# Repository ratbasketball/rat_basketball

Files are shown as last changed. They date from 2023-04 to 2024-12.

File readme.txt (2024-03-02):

## Installation Instructions

# Start with a fresh install of Raspberry Pi OS (legacy, 64 bit) Debian Bullseye & Update System Packages:
sudo apt update && sudo apt upgrade -y

# Install or Upgrade pygame and pygame_menu
pip install --upgrade --force-reinstall pygame==2.3.0 

# Install RPi.GPIO
sudo pip install RPi.GPIO

# Install SDL2 Dependencies
sudo apt-get install libsdl2-mixer-2.0-0 python3-sdl2

# Without installing the above packages, you will encounter errors
# loading the required fonts to run the game, and running the program.  

## Getting the software:

# Clone the repository
git clone https://github.com/ratbasketball/rat_basketball.git

# Move Python files to the desktop
mv rat_basketball/*.py ~/Desktop/

# Clean up by removing the repository folder (optional)
rm -rf rat_basketball

## Game instructions
# Execute the file ratbasketball.py from your desktop.  
# Modify the controls.py file if necessary for your controller.

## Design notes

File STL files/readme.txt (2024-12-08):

The following is a list of 3d printed components available as .stl files in this directory:

hoop components:

	hoop.stl
	
	sensor arm v3.stl or sensor arm v4.stl
		Sensor arm v4 provides an inverted signal, while remaining otherwise identical to sensor arm v3.  
		
General components:

	pellet duct.stl: This allows the trainer to pass pellets or food to the rats
	
	get light filter slot.stl:  This part allows you to slide a gel light filter in front of an led light, to change the stimuli color.

All objects have been tested printed at 100% infill.

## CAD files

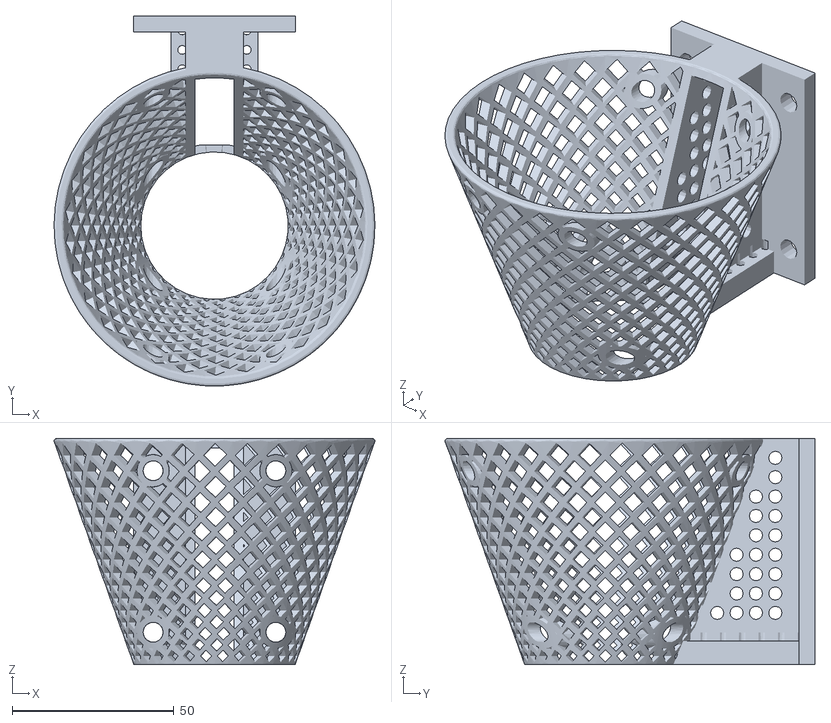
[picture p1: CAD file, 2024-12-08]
STL files/HOOP_v2.stl
99.3 x 114.5 x 70.0

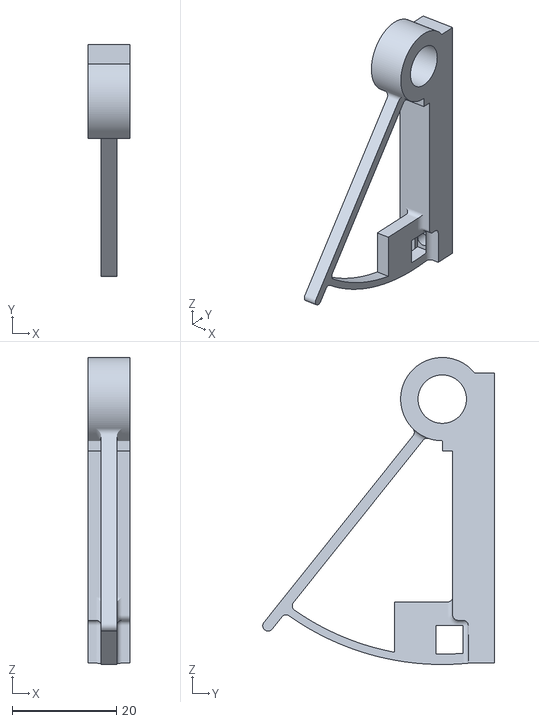
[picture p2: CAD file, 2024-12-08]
STL files/sensor arm v4.stl
8.00 x 44.5 x 59.0

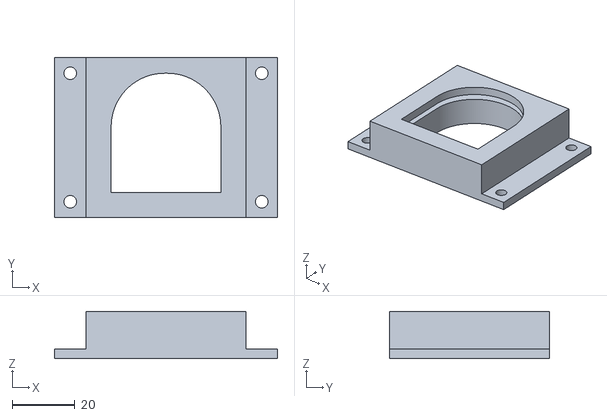
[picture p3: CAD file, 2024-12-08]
STL files/gel light filter slot.stl
70.8 x 50.8 x 15.0

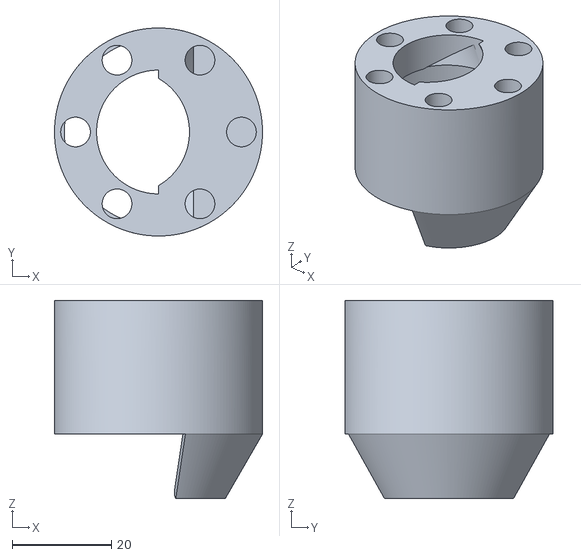
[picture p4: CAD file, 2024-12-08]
STL files/pellet duct.stl
42.0 x 42.0 x 40.0

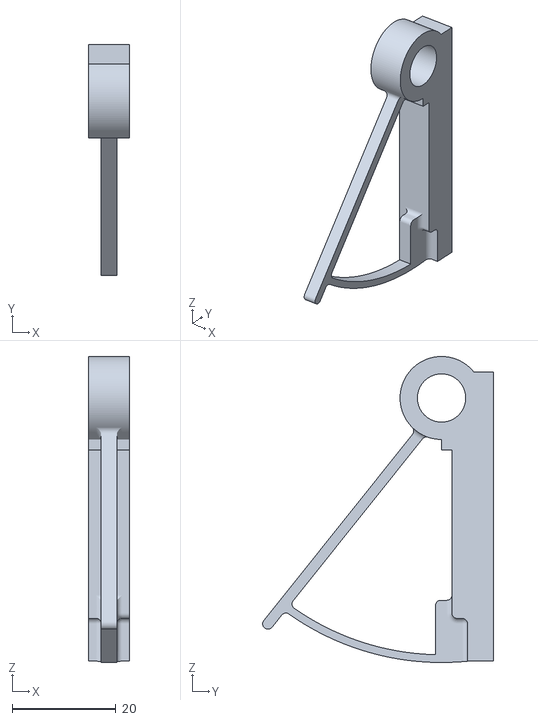
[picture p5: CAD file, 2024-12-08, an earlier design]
STL files/Archive/sensor arm v3.stl
8.00 x 44.5 x 59.0

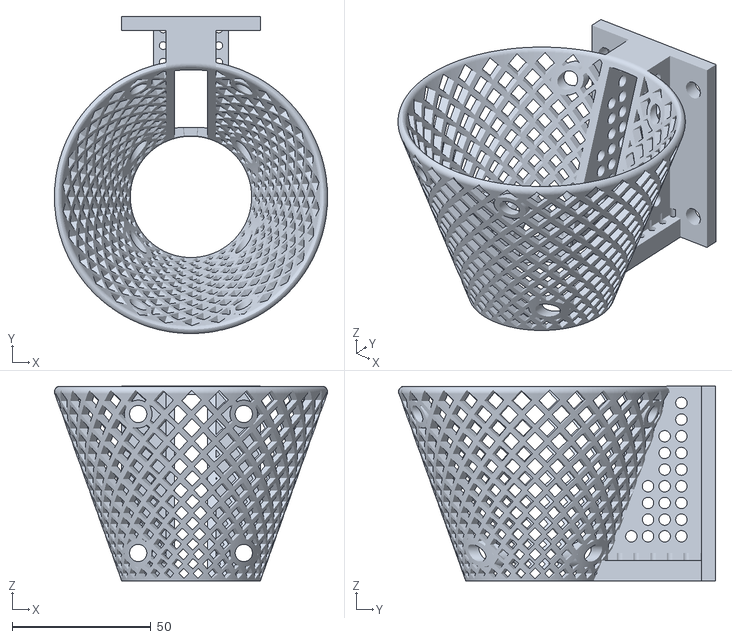
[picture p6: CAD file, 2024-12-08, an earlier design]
STL files/Archive/hoop_small_diameter_exit.stl
98.3 x 114.1 x 70.0

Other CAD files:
Hoop assembly/684AZZ Ball.ipt
Hoop assembly/684AZZ Inner Ring.ipt
Hoop assembly/684AZZ Outer Ring.ipt
Hoop assembly/684AZZ Shield1.ipt
Hoop assembly/684AZZ Shield2.ipt
Hoop assembly/684AZZ.iam
Hoop assembly/DIN EN ISO 4762 - M4 x 25.ipt
Hoop assembly/HOOP.ipt
Hoop assembly/HOOP_v2_enlarged_bottom_hole.ipt
Hoop assembly/IR sensorIR Optical Sensor Module.ipt
Hoop assembly/ISO 4032 - M4 - ISO.ipt
Hoop assembly/ISO 7089 - 4 - 140 HV(1).ipt
Hoop assembly/OldVersions/HOOP.0002.ipt
Hoop assembly/OldVersions/hoop assembly.0015.iam
Hoop assembly/OldVersions/sensor arm v3.0002.ipt
Hoop assembly/hoop assembly.iam
Hoop assembly/sensor arm v3.ipt

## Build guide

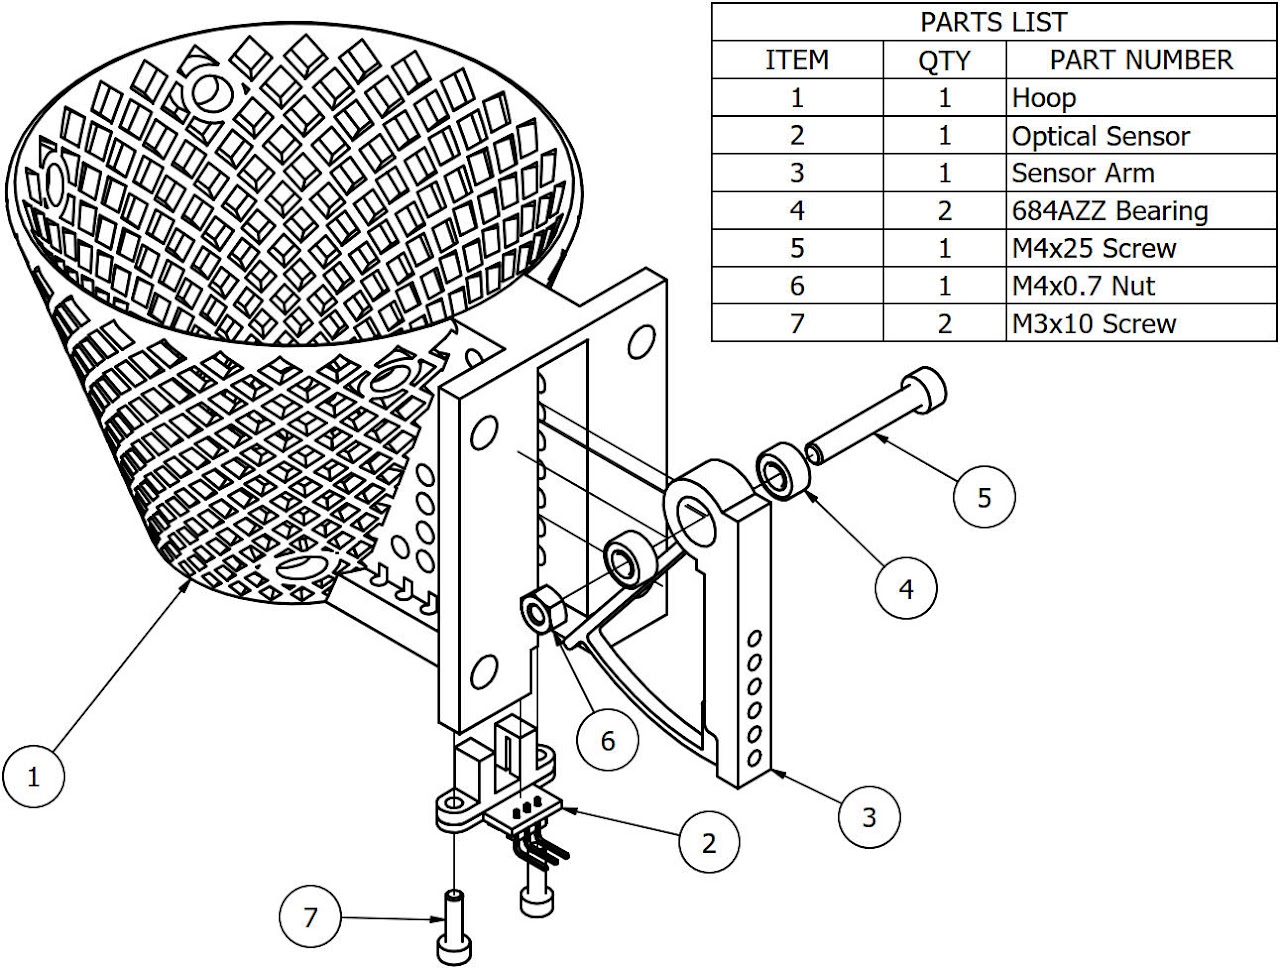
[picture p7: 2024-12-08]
Hoop assembly/media.jpg

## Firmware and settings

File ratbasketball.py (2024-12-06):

import os
os.environ["SDL_VIDEO_ALLOW_SCREENSAVER"] = "1"
os.environ["SDL_JOYSTICK_ALLOW_BACKGROUND_EVENTS"] = "1"
os.environ["SDL_VIDEO_X11_NET_WM_BYPASS_COMPOSITOR"] = "0"
import pygame
from pygame.locals import *
import math
import sys
import pygame_menu
from pygame_menu import themes
import RPi.GPIO as GPIO
import pigpio


#Recall: I did need to go into the controls.py file and edit it to function with my NES controllers
# I need to edit it to the following: 

# Joy pad
# JOY_AXIS_X = 0
# JOY_AXIS_Y = 1
# JOY_BUTTON_BACK = 2
# JOY_BUTTON_SELECT = 1
# JOY_DEADZONE = 0.5
# JOY_DELAY = 300  # ms
# JOY_DOWN = (0, -1)
# JOY_LEFT = (-1, 0)
# JOY_REPEAT = 100  # ms
# JOY_RIGHT = (1, 0)
# JOY_UP = (0, 1)

# initialize pygame stuff
pygame.init()
pygame.font.init()
pygame.joystick.init()

# Initialize some variables and stuff
joysticks = {}
gameTimerMinutes = 0 # unless altered in the start menu
player1Score = 0
player2Score = 0

# setup the game, this code will run only once
pygame.display.set_caption("Rat Basketball")  # see: https://www.pygame.org/docs/ref/display.html
# Note: use full screen below whenever possible, as the font
# will render without exiting the screen.  If necessary, edit font size
# screen = pygame.display.set_mode((0, 0), pygame.FULLSCREEN,display=0) 
screen = pygame.display.set_mode((900, 700), pygame.RESIZABLE)
X,Y = screen.get_width(), screen.get_height()
BLACK = (0, 0, 0)
RED = (255, 0, 0)
GREEN = (0, 255, 0)
BLUE = (0, 0, 255)
GRAY = (200, 200, 200)
background = GRAY 
screen.fill(background)

# setup score board text stuff
player1Name = 'Player 1'
player2Name = 'Player 2'
sysfont = pygame.font.get_default_font()
font = pygame.font.SysFont(None, 48)

playerNameFont = pygame.font.SysFont(None, 250) # may need to make this dynamically updatable
playerScoreFont = pygame.font.SysFont(None, 550) # may need to make this dynamically updatable
timerFont = pygame.font.SysFont(None, 300) # may need to make this dynamically updatable

##############
###  GPIO  ###
##############

pi = pigpio.pi('soft', 8888)
# Time Constants
BUTTON_PRESS_DELAY = 0.3 # Delay between each button press
STEADY_SIGNAL_MICROSECONDS = 300000 # Microseconds needed to trigger a steady electrical signal (avoid false triggers)
lightOnTimeSeconds = 1
lightOnTimeMilliseconds = lightOnTimeSeconds * 1000
player1LightTimeLock = 0
player2LightTimeLock = 0

# GPIO Constants
GPIO_INPUT_P1BASKET = 7 # IO4 on breakout hat CE1 GPIO23 Player 1 - Button A --> Was 12 (GPIO18) before
GPIO_OUTPUT_P1LIGHT = 10 #GPIO 15  UART0 RX
GPIO_INPUT_P2BASKET = 29  # GPIO 05 # GPIO24 Player 1 - Button B #GPIO_INPUT_P2BASKET = 18 # GPIO24 Player 1 - Button B
GPIO_OUTPUT_P2LIGHT = 32 #GPIO 12

# GPIO inputs & outputs configuration
GPIO.setmode(GPIO.BOARD)
GPIO.setwarnings(False)
GPIO.setup(GPIO_OUTPUT_P1LIGHT, GPIO.OUT)
GPIO.setup(GPIO_OUTPUT_P2LIGHT, GPIO.OUT)
GPIO.setup(GPIO_INPUT_P1BASKET, GPIO.IN, pull_up_down=GPIO.PUD_UP)
GPIO.setup(GPIO_INPUT_P2BASKET, GPIO.IN, pull_up_down=GPIO.PUD_UP)

# The below sets up the basket toggle which makes it so that 
# after the basket is activated it will not activate again
# until the switch is turned off 
player1BasketToggle = 0
player2BasketToggle = 0

    
# check GPIO inputs and alter variables such as score accordingly
def gpioInput():
    global player1Score, player2Score, player1BasketToggle, player2BasketToggle
    input_state_P1BASKET = GPIO.input(GPIO_INPUT_P1BASKET)
    input_state_P2BASKET = GPIO.input(GPIO_INPUT_P2BASKET)
    # Define these inside function or outside function?  Let's try both!    
    if input_state_P1BASKET == False and player1BasketToggle == 0:
        #if input_state_P1BASKET == False:
        player1Score = player1Score + 1
        player1BasketToggle = 1
        gpioOutput(1)
        print('Player 1 Basket')
    if input_state_P1BASKET == True:
        #print('p1 basket off')
        player1BasketToggle = 0
    # if input_state_P2BASKET == False and player2BasketToggle == 0:
    if input_state_P2BASKET == False and player2BasketToggle == 0:
        print('Player 2 Basket')
        print('player 2 toggle' + str(player2BasketToggle))
        player2Score = player2Score + 1
        player2BasketToggle = 1
        gpioOutput(2)
    if input_state_P2BASKET == True:
        # print('p2 basket off')
        player2BasketToggle = 0

# We can safely ignore the events that we don't need.  Ignoring unneeded events
# helps with debugging, since we can print the events occuring without
# being overwhelmed with unneeded data    
pygame.event.set_blocked((pygame.MOUSEMOTION, pygame.MOUSEBUTTONUP, 
                          pygame.MOUSEBUTTONDOWN,pygame.WINDOWENTER,pygame.WINDOWLEAVE,pygame.WINDOWLEAVE,pygame.WINDOWFOCUSLOST,pygame.WINDOWTAKEFOCUS))

# The below function outputs signals for lights to the GPIO pins
def gpioOutput(player = 0):
    global player1LightTimeLock, player2LightTimeLock
    if player == 1:
        if pygame.time.get_ticks() >= player1LightTimeLock: 
            GPIO.output(GPIO_OUTPUT_P1LIGHT, GPIO.HIGH) # GPIO 10
            player1LightTimeLock = pygame.time.get_ticks() + lightOnTimeMilliseconds
    if player == 2:
        if pygame.time.get_ticks() >= player2LightTimeLock: 
            GPIO.output(GPIO_OUTPUT_P2LIGHT, GPIO.HIGH)
            player2LightTimeLock = pygame.time.get_ticks() + lightOnTimeMilliseconds
    if player == 0:
        if pygame.time.get_ticks() >= player1LightTimeLock: 
            GPIO.output(GPIO_OUTPUT_P1LIGHT, GPIO.LOW)
        if pygame.time.get_ticks() >= player2LightTimeLock: 
            GPIO.output(GPIO_OUTPUT_P2LIGHT, GPIO.LOW)


def main(gameTimerMinutes, start_ticks):
    clock = pygame.time.Clock()
    # This dict can be left as-is, since pygame will generate a
    # pygame.JOYDEVICEADDED event for every joystick connected
    # at the start of the program.
    joysticks = {}

    done = False
    while not done:
        # Grab Global Variables that we want inside our loop
        global player1Score, player2Score
        gameEndTime = start_ticks + (gameTimerMinutes * 60000)
        timeRemaining = gameEndTime - pygame.time.get_ticks()
        minutesRemaining = math.floor(timeRemaining/60000)
        secondsRemaining = math.floor(timeRemaining/1000)-(minutesRemaining * 60)
        # Event processing step.
        for event in pygame.event.get():
            print(event)
            
            if event.type == pygame.QUIT:
                print('line 170')
                quitGame()

            if event.type == pygame.JOYBUTTONDOWN:
                # A = 1, B = 2,  Start = 9, select = 8
                if event.dict.get('joy')==0:
                    if event.button == 1:
                        gpioOutput(1)
                    
                if event.dict.get('joy')==1:
                    if event.button == 1:
                        gpioOutput(2)

                if event.button == 9:
                    mainMenuShow()
                
            if event.type == pygame.JOYAXISMOTION:
                if event.dict.get('joy')==0:
                    if round(event.dict['value']) == -1 and (event.dict['axis']) == 1: #note: axis is inverted.  Please use -1 for up
                        player1Score = player1Score + 1
                        gpioOutput(1)
                        
                    if round(event.dict['value']) == 1 and (event.dict['axis']) == 1: #note: axis is inverted.  Please use -1 for up
                        player1Score = player1Score - 1
                        if player1Score < 0:
                            player1Score = 0
                            
                if event.dict.get('joy')==1:
                    if round(event.dict['value']) == -1 and (event.dict['axis']) == 1: #note: axis is inverted.  Please use -1 for up
                        player2Score = player2Score + 1
                        gpioOutput(2)
                        
                    if round(event.dict['value']) == 1 and (event.dict['axis']) == 1: #note: axis is inverted.  Please use -1 for up
                        player2Score = player2Score - 1
                        if player1Score < 0:
                            player2Score = 0

            # Handle hotplugging
            if event.type == pygame.JOYDEVICEADDED:
                joy = pygame.joystick.Joystick(event.device_index)
                joysticks[joy.get_instance_id()] = joy
                print(f"Joystick {joy.get_instance_id()} connencted")

            if event.type == pygame.JOYDEVICEREMOVED:
                del joysticks[event.instance_id]
                print(f"Joystick {event.instance_id} disconnected")
                
            if event.type == KEYDOWN and event.key in [K_ESCAPE, K_q,]:
                quitGame()

        # Go ahead and update the screen with what we've draw and limit to 30 frames per second.
        clock.tick(30)
        drawDisplay(minutesRemaining,secondsRemaining,timeRemaining)
        gpioInput()
        gpioOutput()

def drawDisplay(minutesRemaining,secondsRemaining,timeRemaining):
    player1ScoreDisplay = playerScoreFont.render(str(player1Score), True, BLACK)
    player1ScoreDisplayRect = player1ScoreDisplay.get_rect()
    player1ScoreDisplayRect.center = (X/4,Y/2)
    player1NameDisplay = playerNameFont.render(player1Name, True, BLACK)
    player1NameDisplayRect = player1NameDisplay.get_rect()
    player1NameDisplayRect.center = (X/4,Y/10)
    
    player2ScoreDisplay = playerScoreFont.render(str(player2Score), True, BLACK)
    player2ScoreDisplayRect = player2ScoreDisplay.get_rect()
    player2ScoreDisplayRect.center = (3*(X/4),Y/2)
    player2NameDisplay = playerNameFont.render(player2Name, True, BLACK)
    player2NameDisplayRect = player2NameDisplay.get_rect()
    player2NameDisplayRect.center = (3*(X/4),Y/10)
    
    twoDigitSeconds = ("%02d" % (secondsRemaining,))
    timeRemainingDisplay = timerFont.render((str(minutesRemaining) + ':' + str(twoDigitSeconds) ), True, BLACK)
    timeRemainingDisplayRect = timeRemainingDisplay.get_rect()
    timeRemainingDisplayRect.center = (X/2,Y-(Y/10))

    # Drawing step
    # First, clear the screen to white. Don't put other drawing commands
    # above this, or they will be erased with this command.
    screen.fill(background)
    # Now we can send our data to the screen
    screen.blit(player1NameDisplay, player1NameDisplayRect)
    screen.blit(player2NameDisplay, player2NameDisplayRect)
    screen.blit(player1ScoreDisplay, player1ScoreDisplayRect)
    screen.blit(player2ScoreDisplay, player2ScoreDisplayRect)
    if timeRemaining >= 0: # Do not draw time clock if time is <= 0
        screen.blit(timeRemainingDisplay, timeRemainingDisplayRect)

    pygame.display.flip()
    pygame.display.update()


def quitGame():
    print('line 286')
    GPIO.cleanup() 
    pygame.quit()
    sys.exit()
    
def mainMenuShow():
    for event in pygame.event.get():
    # Handle Joystick hotplugging
        if event.type == pygame.JOYDEVICEADDED:
            joy = pygame.joystick.Joystick(event.device_index)
            joysticks[joy.get_instance_id()] = joy
            print(f"Joystick {joy.get_instance_id()} connencted")
        if event.type == pygame.JOYDEVICEREMOVED:
            del joysticks[event.instance_id]
            print(f"Joystick {event.instance_id} disconnected")
    
    def start_the_game():
        start_ticks = pygame.time.get_ticks()
        main(gameTimerMinutes,start_ticks)
    
    def advanced_menu():
        mainmenu._open(advanced)
        
    def setGameTimer(value, minutes):
        global timeRemaining, gameTimerMinutes
        print(value)
        print(minutes)
        # gameEndTime = start_ticks + (minutes * 60000)
        timeRemaining = (minutes * 60000)
        gameTimerMinutes = minutes
        print (timeRemaining)
    
    
    mainmenu = pygame_menu.Menu('Welcome to Rat Basketball!', X, Y, theme=themes.THEME_DARK)
    # mainmenu.add.text_input('Player 1 Name: ', default='Player 1')
    # mainmenu.add.text_input('Player 1 Name: ', default='Player 2')
    mainmenu.add.selector('Game Time (minutes, 0 is infinite): ', [('0', 0),('1', 1), ('2', 2), ('3', 3), ('4', 4), ('5', 5), ('6', 6), ('7', 7), ('8', 8), ('9', 9), ('10', 10)], onchange=setGameTimer)
    mainmenu.add.button('Play', start_the_game)
    # mainmenu.add.button('Advanced Options', advanced_menu)
    mainmenu.add.button('Quit', quitGame)  #mainmenu.add.button('Quit', pygame_menu.events.EXIT)
    # TODO: complete advanced functionality
    # advanced = pygame_menu.Menu('Advanced Options', X, Y, theme=themes.THEME_BLUE)
    # advanced.add.selector('Auto Score :', [('On', 1), ('Off', 0)])  #onchange=set_Autoscore)
    # advanced.add.selector('Auto Feed :', [('On', 1), ('Off', 0)])  #onchange=set_Autoscore)
    # advanced.add.selector('Auto Reinforce (light) :', [('On', 1), ('Off', 0)])  #onchange=set_Autoscore)
    # advanced.add.selector('Auto Light Time): ', [('0', 0),('1', 1), ('2', 2), ('3', 3), ('4', 4), ('5', 5), ('6', 6), ('7', 7), ('8', 8), ('9', 9), ('10', 10)])
    # advanced.add.selector('Score Sound :', [('On', 1), ('Off', 0)])  #onchange=set_Autoscore)
    # advanced.add.selector('Auto Feed :', [('On', 1), ('Off', 0)])  #onchange=set_Autoscore)
    # advanced.add.button('Back', mainMenuShow)
    
    # let's draw an arrow on the screen to highlight our selection    
    arrow = pygame_menu.widgets.LeftArrowSelection(arrow_size = (10, 15))
    
    while True:
        events = pygame.event.get()
        for event in events:
            if event.type == pygame.QUIT:
                print('line 353')
                quitGame()
    
        if mainmenu.is_enabled():
            mainmenu.update(events)
            mainmenu.draw(screen)
            if (mainmenu.get_current().get_selected_widget()):
                arrow.draw(screen, mainmenu.get_current().get_selected_widget())
    
        pygame.display.update()   

while True:  
    mainMenuShow()

# The below sould never happen.  TODO: program the bellow to be an exception
# to show errors if applicable.  
print('This should have never happened!  Please check configuration')

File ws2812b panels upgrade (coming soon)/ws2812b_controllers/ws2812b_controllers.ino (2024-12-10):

#include <Adafruit_NeoPixel.h>

#define PIN            6   // Pin connected to the data input of both WS2812B panels
#define NUM_PIXELS    128 // Total number of pixels (64 for panel 1, 64 for panel 2)

Adafruit_NeoPixel strip = Adafruit_NeoPixel(NUM_PIXELS, PIN, NEO_GRB + NEO_KHZ800);

// Structure to hold the state of each panel
struct Panel {
  int r, g, b;           // Color
  int brightness;        // Brightness
  unsigned long turnOffTime;  // Time at which to turn off (0 means stay on indefinitely)
};

Panel panels[2];  // Array to hold states of two panels (panel 1 and panel 2)

void setup() {
  // Start serial communication
  Serial.begin(9600);

  // Initialize the WS2812B panels
  strip.begin();
  strip.show(); // Initialize all pixels to "off"

  // Initialize the panels with default values (you can customize this)
  for (int i = 0; i < 2; i++) {
    panels[i].r = 0;
    panels[i].g = 0;
    panels[i].b = 0;
    panels[i].brightness = 255;
    panels[i].turnOffTime = 0;
  }
}

void loop() {
  // Check if new data is available on the serial port
  if (Serial.available() > 0) {
    // Read the incoming data as a string
    String command = Serial.readStringUntil('\n');
    command.trim();  // Remove any leading or trailing whitespace

    // Parse the command string into panel number, r, g, b, brightness, and duration
    int panelNum = -1, r = -1, g = -1, b = -1, brightness = -1, duration = -1;
    int numParams = sscanf(command.c_str(), "panel %d %d %d %d %d %d", &panelNum, &r, &g, &b, &brightness, &duration);

    // If the panel number is valid and the command is complete
    if (numParams == 6 && panelNum >= 1 && panelNum <= 2 && r >= 0 && g >= 0 && b >= 0 && brightness >= 0) {
      // Update the selected panel's state
      panelNum--; // Convert to zero-based index
      panels[panelNum].r = r;
      panels[panelNum].g = g;
      panels[panelNum].b = b;
      panels[panelNum].brightness = brightness;

      // Set the brightness of the panel
      strip.setBrightness(brightness);

      // Light up the selected panel
      for (int i = 0; i < NUM_PIXELS; i++) {
        if (panelNum == 0 && i < 64) { // First panel: Pixels 0-63
          strip.setPixelColor(i, strip.Color(r, g, b));
        } else if (panelNum == 1 && i >= 64) { // Second panel: Pixels 64-127
          strip.setPixelColor(i, strip.Color(r, g, b));
        }
      }
      strip.show();  // Update the panels with the new color

      // Handle duration: -1 means stay on indefinitely
      if (duration == -1) {
        panels[panelNum].turnOffTime = 0; // Indicate no turn-off time
      } else {
        // Set the turn-off time based on the current time and the duration
        panels[panelNum].turnOffTime = millis() + duration;
      }
    }
    else {
      // Handle invalid command
      Serial.println("Invalid command format, use: panel <1 or 2> r g b brightness duration");
    }
  }

  // Check if it's time to turn off the LEDs for any panel
  for (int i = 0; i < 2; i++) {
    if (panels[i].turnOffTime != 0 && millis() >= panels[i].turnOffTime) {
      // Turn off the selected panel
      if (i == 0) { // First panel: Pixels 0-63
        for (int j = 0; j < 64; j++) {
          strip.setPixelColor(j, strip.Color(0, 0, 0));
        }
      } else if (i == 1) { // Second panel: Pixels 64-127
        for (int j = 64; j < 128; j++) {
          strip.setPixelColor(j, strip.Color(0, 0, 0));
        }
      }
      strip.show();  // Update the panel to turn off
      panels[i].turnOffTime = 0; // Reset the turn-off time
    }
  }
}

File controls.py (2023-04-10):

"""
NOTE: This controls.py file works for the NES USB controller.  It will not work with other controllers without modification.
Further, some controllers require no modification to the controls.py file in the pygame_menu library
the library could typically be found:  /home/(User Name)/.local/lib/python3.9/site-packages/pygame_menu
if you have an NES controller you can simply replace the file with this one

pygame-menu
https://github.com/ppizarror/pygame-menu

CONTROLS
Default controls of Menu object and key definition.
"""

__all__ = [

    # Joy pad
    'JOY_AXIS_X',
    'JOY_AXIS_Y',
    'JOY_BUTTON_BACK',
    'JOY_BUTTON_SELECT',
    'JOY_DEADZONE',
    'JOY_DELAY',
    'JOY_DOWN',
    'JOY_LEFT',
    'JOY_REPEAT',
    'JOY_RIGHT',
    'JOY_UP',

    # Keyboard events
    'KEY_APPLY',
    'KEY_BACK',
    'KEY_CLOSE_MENU',
    'KEY_LEFT',
    'KEY_MOVE_DOWN',
    'KEY_MOVE_UP',
    'KEY_RIGHT',

    # Controller object
    'Controller'

]

# Imports
# noinspection PyUnresolvedReferences
import pygame_menu
import pygame.locals as _locals
from pygame.event import Event as EventType
from typing import Union

WidgetType = Union['pygame_menu.Menu', 'pygame_menu.widgets.Widget']

# Joy pad
JOY_AXIS_X = 0
JOY_AXIS_Y = 1
JOY_BUTTON_BACK = 2
JOY_BUTTON_SELECT = 1
JOY_DEADZONE = 0.5
JOY_DELAY = 300  # ms
JOY_DOWN = (0, -1)
JOY_LEFT = (-1, 0)
JOY_REPEAT = 100  # ms
JOY_RIGHT = (1, 0)
JOY_UP = (0, 1)

# Keyboard events
KEY_APPLY = _locals.K_RETURN
KEY_BACK = _locals.K_BACKSPACE
KEY_CLOSE_MENU = _locals.K_ESCAPE
KEY_LEFT = _locals.K_LEFT
KEY_MOVE_DOWN = _locals.K_UP
KEY_MOVE_UP = _locals.K_DOWN  # Consider keys are "inverted"
KEY_RIGHT = _locals.K_RIGHT
KEY_TAB = _locals.K_TAB


# noinspection PyUnusedLocal
class Controller(object):
    """
    Controller class. Accepts any object and provides functions to handle each
    event.
    """
    joy_delay: int
    joy_repeat: int

    def __init__(self) -> None:
        self.joy_delay = JOY_DELAY
        self.joy_repeat = JOY_REPEAT

    @staticmethod
    def apply(event: EventType, widget: WidgetType) -> bool:
        """
        Accepts apply key. Requires ``pygame.KEYDOWN``.

        :param event: Event
        :param widget: Widget that accepts the event
        :return: True if event matches
        """
        return event.key == KEY_APPLY

    @staticmethod
    def back(event: EventType, widget: WidgetType) -> bool:
        """
        Accepts back key. Requires ``pygame.KEYDOWN``.

        :param event: Event
        :param widget: Widget that accepts the event
        :return: True if event matches
        """
        return event.key == KEY_BACK

    @staticmethod
    def close_menu(event: EventType, widget: WidgetType) -> bool:
        """
        Accepts close menu key. Requires ``pygame.KEYDOWN``.

        :param event: Event
        :param widget: Widget that accepts the event
        :return: True if event matches
        """
        return event.key == KEY_CLOSE_MENU

    @staticmethod
    def delete(event: EventType, widget: WidgetType) -> bool:
        """
        Accepts delete key. Requires ``pygame.KEYDOWN``.

        :param event: Event
        :param widget: Widget that accepts the event
        :return: True if event matches
        """
        return event.key == _locals.K_DELETE

    @staticmethod
    def end(event: EventType, widget: WidgetType) -> bool:
        """
        Accepts end key. Requires ``pygame.KEYDOWN``.

        :param event: Event
        :param widget: Widget that accepts the event
        :return: True if event matches
        """
        return event.key == _locals.K_END

    @staticmethod
    def escape(event: EventType, widget: WidgetType) -> bool:
        """
        Accepts escape key. Requires ``pygame.KEYDOWN``.

        :param event: Event
        :param widget: Widget that accepts the event
        :return: True if event matches
        """
        return event.key == _locals.K_ESCAPE

    @staticmethod
    def home(event: EventType, widget: WidgetType) -> bool:
        """
        Accepts home key. Requires ``pygame.KEYDOWN``.

        :param event: Event
        :param widget: Widget that accepts the event
        :return: True if event matches
        """
        return event.key == _locals.K_HOME

    @staticmethod
    def joy_axis_x_left(event: EventType, widget: WidgetType) -> bool:
        """
        Accepts joy movement on x-axis (left direction). Requires ``pygame.JOYAXISMOTION``.

        :param event: Event
        :param widget: Widget that accepts the event
        :return: True if event matches
        """
        return event.axis == JOY_AXIS_X and event.value < -JOY_DEADZONE

    @staticmethod
    def joy_axis_x_right(event: EventType, widget: WidgetType) -> bool:
        """
        Accepts joy movement on x-axis (right direction). Requires ``pygame.JOYAXISMOTION``.

        :param event: Event
        :param widget: Widget that accepts the event
        :return: True if event matches
        """
        return event.axis == JOY_AXIS_X and event.value > JOY_DEADZONE

    @staticmethod
    def joy_axis_y_down(event: EventType, widget: WidgetType) -> bool:
        """
        Accepts joy movement on y-axis (down direction). Requires ``pygame.JOYAXISMOTION``.

        :param event: Event
        :param widget: Widget that accepts the event
        :return: True if event matches
        """
        return event.axis == JOY_AXIS_Y and event.value > JOY_DEADZONE

    @staticmethod
    def joy_axis_y_up(event: EventType, widget: WidgetType) -> bool:
        """
        Accepts joy movement on y-axis (up direction). Requires ``pygame.JOYAXISMOTION``.

        :param event: Event
        :param widget: Widget that accepts the event
        :return: True if event matches
        """
        return event.axis == JOY_AXIS_Y and event.value < -JOY_DEADZONE

    @staticmethod
    def joy_back(event: EventType, widget: WidgetType) -> bool:
        """
        Accepts joy back button. Requires ``pygame.JOYBUTTONDOWN``.

        :param event: Event
        :param widget: Widget that accepts the event
        :return: True if event matches
        """
        return event.button == JOY_BUTTON_BACK

    @staticmethod
    def joy_down(event: EventType, widget: WidgetType) -> bool:
        """
        Accepts joy movement to down direction. Requires ``pygame.JOYHATMOTION``.

        :param event: Event
        :param widget: Widget that accepts the event
        :return: True if event matches
        """
        return event.value == JOY_DOWN

    @staticmethod
    def joy_left(event: EventType, widget: WidgetType) -> bool:
        """
        Accepts joy movement to left direction. Requires ``pygame.JOYHATMOTION``.

        :param event: Event
        :param widget: Widget that accepts the event
        :return: True if event matches
        """
        return event.value == JOY_LEFT
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

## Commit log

2023-10-13 Added 3d files to complete box
    Added 3d files to complete box
    [684AZZ Ball.ipt, 684AZZ Inner Ring.ipt, 684AZZ Outer Ring.ipt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]
2024-12-06 Increased hoop bottom hole diameter to allow passage of slightly chewed or oversized balls
    [HOOP.0002.ipt, HOOP.ipt, HOOP_v2_enlarged_bottom_hole.ipt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]
2024-12-08 Made arduino code and jupyter notebook to control ws2812b panels
    [HOOP_v2.stl, gel light filter slot.stl, hoop assembly.0013.iam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]
